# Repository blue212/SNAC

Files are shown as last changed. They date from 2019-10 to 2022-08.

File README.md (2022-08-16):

# SNAC
Accessory converter for MiSTer

Serial Native Accessory Converter

SNAC is general purpose level shifter for use with MiSTer. It can be used to power 5v devices and it will safely convert any logic between the 3v3(MiSTer) and 5 device. It will be used mostly for 5v controllers and other peripherals.

The SNAC connects to the User port(formerly Serial I/O port) of the IO board on Mister. I recommend a male to female usb3 extension cable between them.

The SNAC is available in 2 versions the only difference being the connector on the controller side(USB3 or HDMI). Various adapters can then be plugged into that connector. I made various adapter PCBs for use with the USB3 verrsion.

Becasue the SNAC connects to the User port the peripheral connects to the GPIO of the MiSTer, this bypasses all layers the normal usb controllers use. So it's very much like having a controller port for the original system. One benefit of this is that most weird peripherals should work with their cores(like Lightguns etc) which most normal usb converters either don't or can't do. One downside to bypassing the layers is the you can't controle the OSD.

*A mod to the older IO boards is needed if you want to use SEGA peripherals. Analog IO board 6.1 and Digital 1.2 fix this issue and have a jumper near USER port that needs to be set to io6 .

-TODO detail the needed mod

-Updates

Changed the partslist to use a different part for the male USB connector.

Uxcell a19032000ux0260 instead of Wuerth 692112030100

Addded Mini version of the hdmi and USB3 snac boards.

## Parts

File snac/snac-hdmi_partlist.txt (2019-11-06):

Partlist

Part     Value                          Device                         Package                     Library                                                  Sheet

C1       0.1uf                          C_0805                         C0805                       rc-master-smd                                            1
C2       0.1uf                          C_0805                         C0805                       rc-master-smd                                            1
JP1      PINHD-1X10_2.54-S              PINHD-1X10_2.54-S              1X10-S                      pinhead-2                                                1
JP2      PINHD-1X10_2.54-S              PINHD-1X10_2.54-S              1X10-S                      pinhead-2                                                1
JP3                                     JUMPER-2PTH                    1X02                        SparkFun                                                 1
K2       a19032000ux0260                a19032000ux0260                a19032000ux0260           Uxcell 1
K3       685119134923                   685119134923                   685119134923                Wuerth_Elektronik_eiCan_Communication_Connectors_STENCIL 1
Q1       BSS138                         MOSFET-NCHANNELSMD             SOT23-3                     SparkFun                                                 1
Q2       BSS138                         MOSFET-NCHANNELSMD             SOT23-3                     SparkFun                                                 1
Q3       BSS138                         MOSFET-NCHANNELSMD             SOT23-3                     SparkFun                                                 1
Q4       BSS138                         MOSFET-NCHANNELSMD             SOT23-3                     SparkFun                                                 1
Q5       BSS138                         MOSFET-NCHANNELSMD             SOT23-3                     SparkFun                                                 1
Q6       BSS138                         MOSFET-NCHANNELSMD             SOT23-3                     SparkFun                                                 1
Q7       BSS138                         MOSFET-NCHANNELSMD             SOT23-3                     SparkFun                                                 1
Q8       BSS138                         MOSFET-NCHANNELSMD             SOT23-3                     SparkFun                                                 1
R1       10K                            RESISTOR0603-RES               0603-RES                    SparkFun                                                 1
R2       10K                            RESISTOR0603-RES               0603-RES                    SparkFun                                                 1
R3       10K                            RESISTOR0603-RES               0603-RES                    SparkFun                                                 1
R4       10K                            RESISTOR0603-RES               0603-RES                    SparkFun                                                 1
R5       10K                            RESISTOR0603-RES               0603-RES                    SparkFun                                                 1
R6       10K                            RESISTOR0603-RES               0603-RES                    SparkFun                                                 1
R7       10K                            RESISTOR0603-RES               0603-RES                    SparkFun                                                 1
R8       10K                            RESISTOR0603-RES               0603-RES                    SparkFun                                                 1
R9       10K                            RESISTOR0603-RES               0603-RES                    SparkFun                                                 1
R10      10K                            RESISTOR0603-RES               0603-RES                    SparkFun                                                 1
R11      10K                            RESISTOR0603-RES               0603-RES                    SparkFun                                                 1
R12      10K                            RESISTOR0603-RES               0603-RES                    SparkFun                                                 1
R13      10K                            RESISTOR0603-RES               0603-RES                    SparkFun                                                 1
R14      10K                            RESISTOR0603-RES               0603-RES                    SparkFun                                                 1
R15      10K                            RESISTOR0603-RES               0603-RES                    SparkFun                                                 1
R16      10K                            RESISTOR0603-RES               0603-RES                    SparkFun                                                 1
U1       PMIC-LDO-XC6206P332MR-G(SOT23) PMIC-LDO-XC6206P332MR-G(SOT23) SOT-23                      PMIC-LDO-XC6206P332MR-G_SOT23_                           1
X1       JST-XH-02-PIN-ROUND-PAD        JST-XH-02-PIN-ROUND-PAD        JST-XH-02-PACKAGE-ROUND-PAD Rembrandt Electronics - JST XH Connectors v1-0           1

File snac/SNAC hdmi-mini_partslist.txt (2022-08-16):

Partlist

EAGLE Version 7.7.0 Copyright (c) 1988-2016 CadSoft

Assembly variant: 

Part     Value                          Package         Library                          Position (inch)       Orientation

C1       1uf                            C0805           rc-master-smd                    (0.23239998 0.06189998) MR0
C2       1uf                            C0805           rc-master-smd                    (0.42249975 0.062)    MR0
K2       a19032000ux0260                a19032000ux0260 Uxcell 1                         (0.2 0.444)           R90
K3       685119134923                   685119134923    Wuerth_Elektronik                (0.58 0.435)          R90 
Q1       BSS138                         SOT23-3         SparkFun                         (0.722 0.248)         MR90
Q2       BSS138                         SOT23-3         SparkFun                         (0.588 0.55)          MR90
Q3       BSS138                         SOT23-3         SparkFun                         (0.587 0.348)         MR90
Q4       BSS138                         SOT23-3         SparkFun                         (0.729 0.441)         MR90
Q5       BSS138                         SOT23-3         SparkFun                         (0.729 0.628)         MR90
Q6       BSS138                         SOT23-3         SparkFun                         (0.728 0.811)         MR90
Q7       BSS138                         SOT23-3         SparkFun                         (0.737 0.072)         MR90
R1       10K                            0603-RES        SparkFun                         (0.242 0.588)         MR180
R2       10K                            0603-RES        SparkFun                         (0.244 0.498)         MR180
R3       10K                            0603-RES        SparkFun                         (0.244 0.411)         MR180
R4       10K                            0603-RES        SparkFun                         (0.85910002 0.24680007) MR0
R5       10K                            0603-RES        SparkFun                         (0.855 0.441)         MR0
R6       10K                            0603-RES        SparkFun                         (0.242 0.671)         MR180
R7       10K                            0603-RES        SparkFun                         (0.859 0.54)          MR0
R8       10K                            0603-RES        SparkFun                         (0.242 0.752)         MR180
R9       10K                            0603-RES        SparkFun                         (0.857 0.63)          MR0
R10      10K                            0603-RES        SparkFun                         (0.854 0.333)         MR0
R11      10K                            0603-RES        SparkFun                         (0.24 0.842)          MR180
R12      10K                            0603-RES        SparkFun                         (0.853 0.812)         MR0
R13      10K                            0603-RES        SparkFun                         (0.242 0.328)         MR180
R14      10K                            0603-RES        SparkFun                         (0.86 0.058)          MR0
U1       PMIC-LDO-XC6206P332MR-G(SOT23) SOT-23          PMIC-LDO-XC6206P332MR-G_SOT23_   (0.299 0.2)           MR0

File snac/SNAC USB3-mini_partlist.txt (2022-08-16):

Partlist

EAGLE Version 7.7.0 Copyright (c) 1988-2016 CadSoft

Assembly variant: 

Part     Value                          Package         Library                          Position (inch)       Orientation

C1       1uf                            C0805           rc-master-smd                   (0.23239998 0.06189998) MR0
C2       1uf                            C0805           rc-master-smd                   (0.42249975 0.062)    MR0
K1       692121030100                   692121030100    Wuerth_Elektronik               (1.86 0.42)           R270
K2       a19032000ux0260                a19032000ux0260 Uxcell                          (0.2 0.42)            R90
Q1       BSS138                         SOT23-3         SparkFun                        (0.734 0.194)         MR90
Q2       BSS138                         SOT23-3         SparkFun                        (0.729 0.565)         MR90
Q3       BSS138                         SOT23-3         SparkFun                        (0.73 0.317)          MR90
Q4       BSS138                         SOT23-3         SparkFun                        (0.729 0.441)         MR90
Q5       BSS138                         SOT23-3         SparkFun                        (0.729 0.689)         MR90
Q6       BSS138                         SOT23-3         SparkFun                        (0.728 0.811)         MR90
Q7       BSS138                         SOT23-3         SparkFun                        (0.731 0.072)         MR90
R1       10K                            0603-RES        SparkFun                        (0.242 0.588)         MR180
R2       10K                            0603-RES        SparkFun                        (0.244 0.498)         MR180
R3       10K                            0603-RES        SparkFun                        (0.244 0.411)         MR180
R4       10K                            0603-RES        SparkFun                        (0.86210002 0.19380007) MR0
R5       10K                            0603-RES        SparkFun                        (0.855 0.441)         MR0
R6       10K                            0603-RES        SparkFun                        (0.242 0.671)         MR180
R7       10K                            0603-RES        SparkFun                        (0.856 0.565)         MR0
R8       10K                            0603-RES        SparkFun                        (0.242 0.752)         MR180
R9       10K                            0603-RES        SparkFun                        (0.853 0.689)         MR0
R10      10K                            0603-RES        SparkFun                        (0.859 0.317)         MR0
R11      10K                            0603-RES        SparkFun                        (0.24 0.842)          MR180
R12      10K                            0603-RES        SparkFun                        (0.853 0.812)         MR0
R13      10K                            0603-RES        SparkFun                        (0.242 0.328)         MR180
R14      10K                            0603-RES        SparkFun                        (0.861 0.071)         MR0
U1       PMIC-LDO-XC6206P332MR-G(SOT23) SOT-23          PMIC-LDO-XC6206P332MR-G_SOT23_  (0.299 0.2)           MR0

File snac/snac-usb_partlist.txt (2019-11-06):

Partlist

Part     Value                          Package                     Library                                                  Position (inch)       Orientation

C1       1uf                            C0805                       rc-master-smd                                            (0.16839998 0.07589998) R0
C2       1uf                            C0805                       rc-master-smd                                            (0.50849975 0.119)    R90
JP1      PINHD-1X10_2.54-S              1X10-S                      pinhead-2                                                (1.08 0.07)           R0
JP2      PINHD-1X10_2.54-S              1X10-S                      pinhead-2                                                (1.09 0.77)           R0
JP3                                     1X02                        SparkFun                                                 (0.393 0.772)         R0
K1       692121030100                   692121030100                Wuerth_Elektronik_eiCan_Communication_Connectors_STENCIL (1.86 0.42)           R270
K2       a19032000ux0260               a19032000ux0260              Uxcell                                                   (0.2 0.42)            R90
Q1       BSS138                         SOT23-3                     SparkFun                                                 (0.567 0.423)         R0
Q2       BSS138                         SOT23-3                     SparkFun                                                 (1.016 0.423)         R0
Q3       BSS138                         SOT23-3                     SparkFun                                                 (0.719 0.423)         R0
Q4       BSS138                         SOT23-3                     SparkFun                                                 (0.868 0.423)         R0
Q5       BSS138                         SOT23-3                     SparkFun                                                 (1.19 0.42)           R0
Q6       BSS138                         SOT23-3                     SparkFun                                                 (1.34 0.42)           R0
Q7       BSS138                         SOT23-3                     SparkFun                                                 (1.49 0.42)           R0
Q8       BSS138                         SOT23-3                     SparkFun                                                 (1.64 0.42)           R0
R1       10K                            0603-RES                    SparkFun                                                 (0.865 0.271)         R0
R2       10K                            0603-RES                    SparkFun                                                 (0.719 0.205)         R0
R3       10K                            0603-RES                    SparkFun                                                 (0.566 0.273)         R0
R4       10K                            0603-RES                    SparkFun                                                 (0.56689998 0.62480007) R180
R5       10K                            0603-RES                    SparkFun                                                 (0.862 0.626)         R180
R6       10K                            0603-RES                    SparkFun                                                 (1.02 0.2)            R0
R7       10K                            0603-RES                    SparkFun                                                 (1.016 0.573)         R180
R8       10K                            0603-RES                    SparkFun                                                 (1.191 0.271)         R0
R9       10K                            0603-RES                    SparkFun                                                 (1.185 0.625)         R0
R10      10K                            0603-RES                    SparkFun                                                 (0.715 0.574)         R180
R11      10K                            0603-RES                    SparkFun                                                 (1.337 0.203)         R0
R12      10K                            0603-RES                    SparkFun                                                 (1.34 0.57)           R0
R13      10K                            0603-RES                    SparkFun                                                 (1.491 0.27)          R0
R14      10K                            0603-RES                    SparkFun                                                 (1.49 0.622)          R0
R15      10K                            0603-RES                    SparkFun                                                 (1.641 0.329)         R0
R16      10K                            0603-RES                    SparkFun                                                 (1.641 0.568)         R0
U1       PMIC-LDO-XC6206P332MR-G(SOT23) SOT-23                      PMIC-LDO-XC6206P332MR-G_SOT23_                           (0.36 0.111)          R0
X1       JST-XH-02-PIN-ROUND-PAD        JST-XH-02-PACKAGE-ROUND-PAD Rembrandt Electronics - JST XH Connectors v1-0           (1.672 0.156)         R270

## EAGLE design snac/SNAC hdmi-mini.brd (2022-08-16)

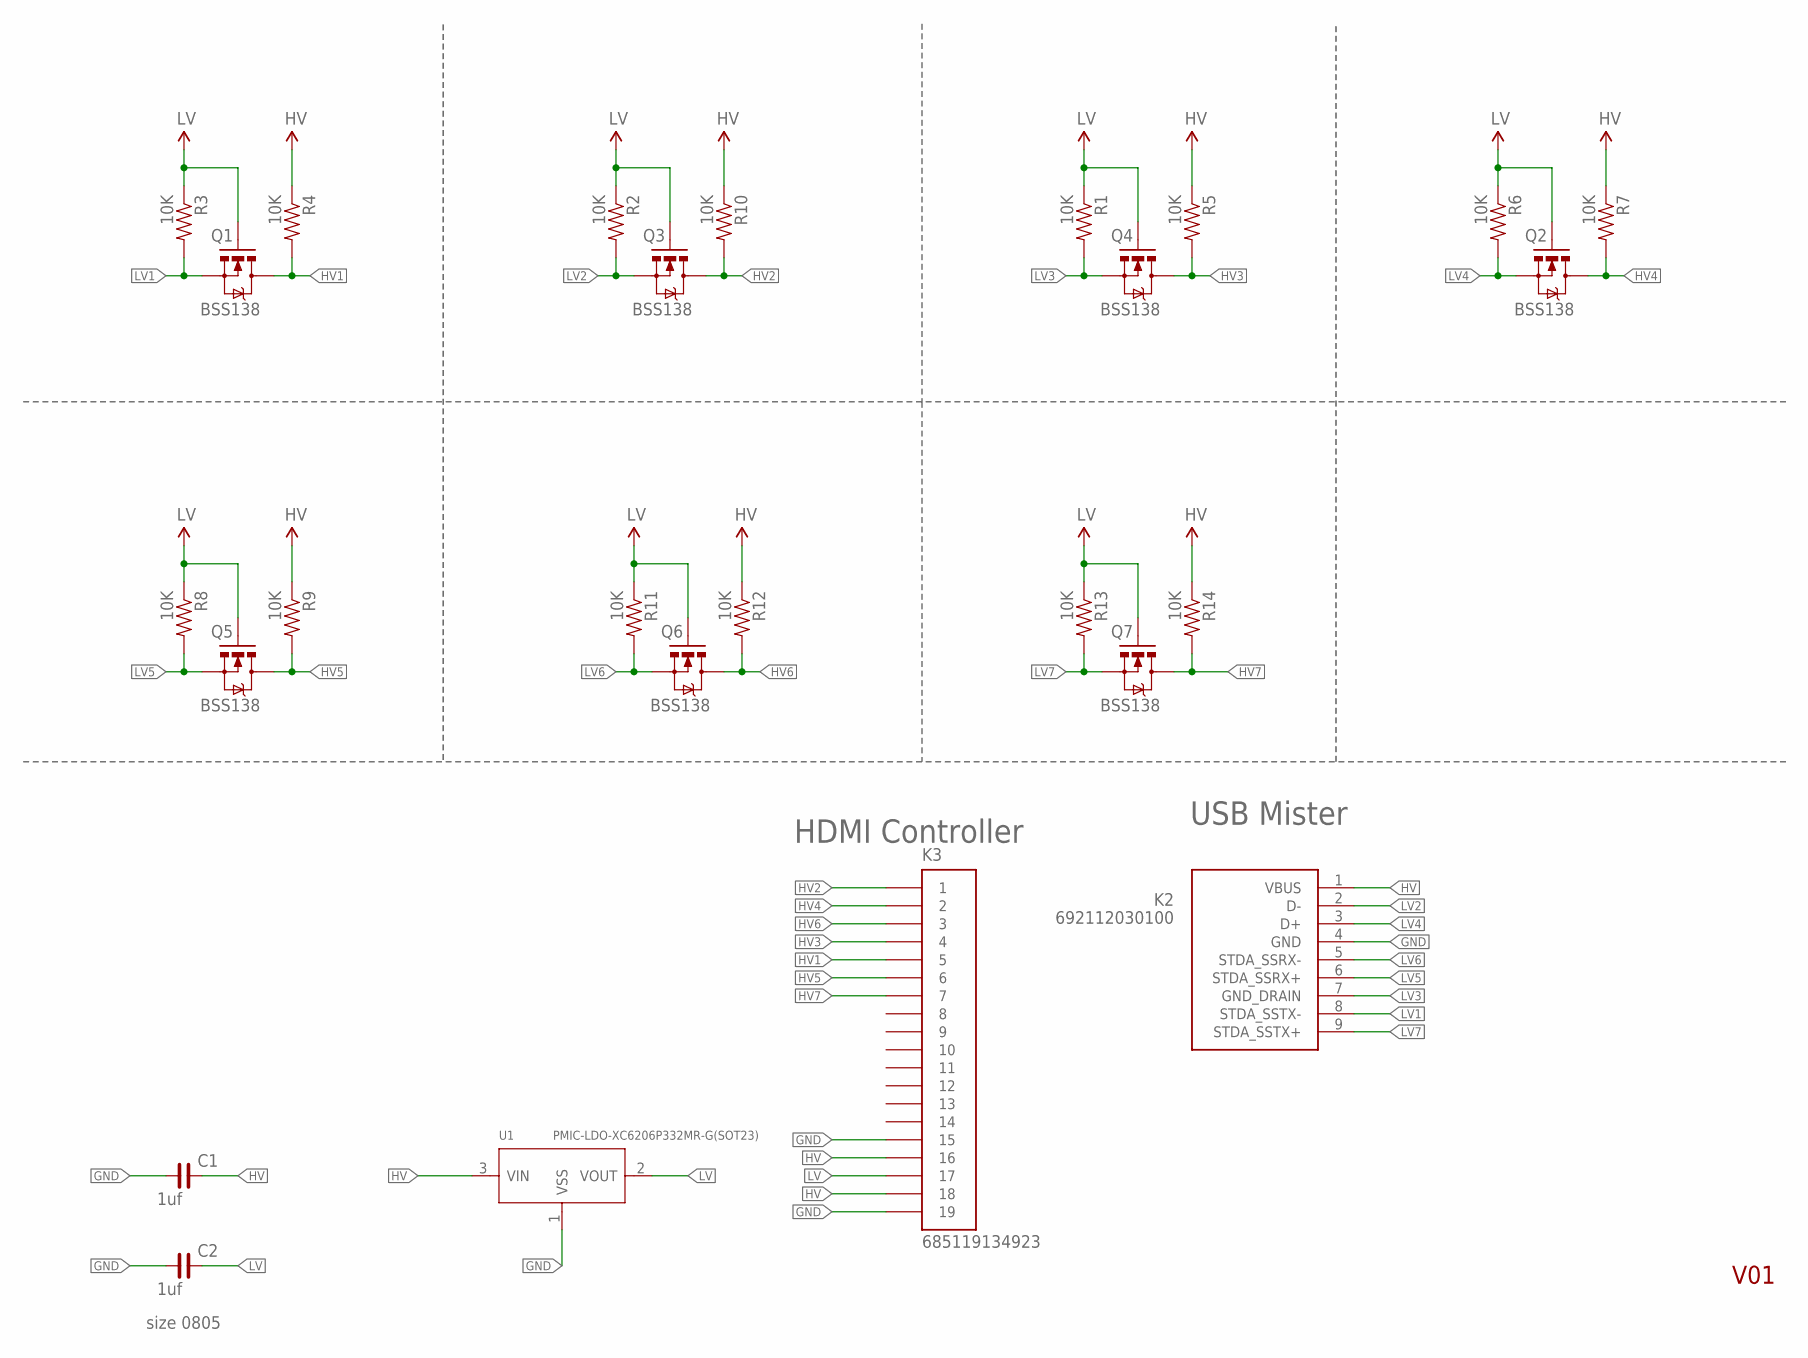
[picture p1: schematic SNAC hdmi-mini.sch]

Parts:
C1, C2: 1uf; C0805
K2: 692112030100
K3: 685119134923
Q1, Q2, Q3, Q4, Q5, Q6, Q7: BSS138; SOT23-3
R1, R2, R3, R4, R5, R6, R7, R8, R9, R10, R11, R12, R13, R14: 10K; 0603-RES
U1: PMIC-LDO-XC6206P332MR-G(SOT23); SOT-23

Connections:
GND: C1.1, C2.1, K2.4 (GND), K3.15, K3.19, U1.1 (VSS)
HV: C1.2, K2.1 (VBUS), K3.16, K3.18, R4.1, R5.1, R7.1, R9.1, R10.1, R12.1, R14.1, U1.3 (VIN)
HV1: K3.5, Q1.3 (D), R4.2
HV2: K3.1, Q3.3 (D), R10.2
HV3: K3.4, Q4.3 (D), R5.2
HV4: K3.2, Q2.3 (D), R7.2
HV5: K3.6, Q5.3 (D), R9.2
HV6: K3.3, Q6.3 (D), R12.2
HV7: K3.7, Q7.3 (D), R14.2
LV: C2.2, K3.17, Q1.1 (G), Q2.1 (G), Q3.1 (G), Q4.1 (G), Q5.1 (G), Q6.1 (G), Q7.1 (G), R1.1, R2.1, R3.1, R6.1, R8.1, R11.1, R13.1, U1.2 (VOUT)
LV1: K2.8 (STDA_SSTX-), Q1.2 (S), R3.2
LV2: K2.2 (D-), Q3.2 (S), R2.2
LV3: K2.7 (GND_DRAIN), Q4.2 (S), R1.2
LV4: K2.3 (D+), Q2.2 (S), R6.2
LV5: K2.6 (STDA_SSRX+), Q5.2 (S), R8.2
LV6: K2.5 (STDA_SSRX-), Q6.2 (S), R11.2
LV7: K2.9 (STDA_SSTX+), Q7.2 (S), R13.2

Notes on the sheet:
V01
USB Mister
size 0805
HDMI Controller

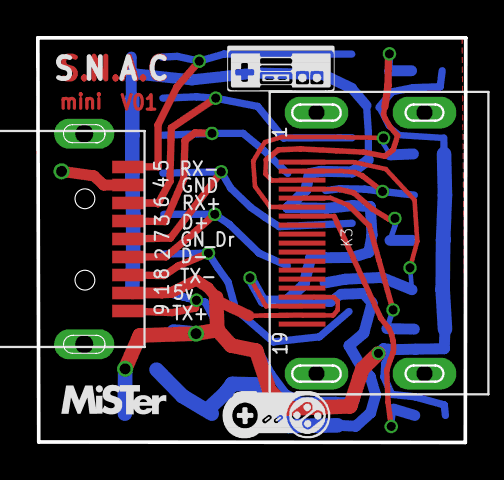
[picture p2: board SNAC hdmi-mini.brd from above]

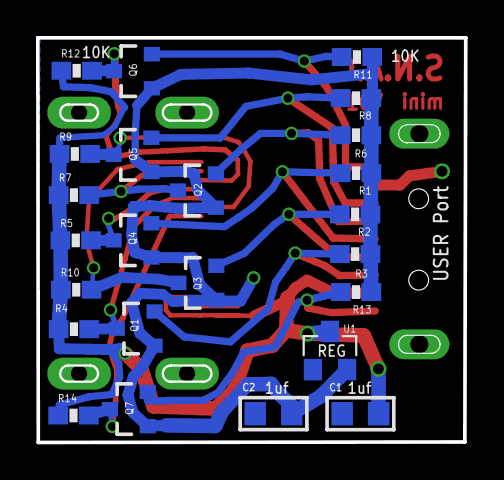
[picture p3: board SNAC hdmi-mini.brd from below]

Board: 2 copper layers, 23.8 x 22.5 mm, 26 parts (24 on the bottom side), 17 nets.

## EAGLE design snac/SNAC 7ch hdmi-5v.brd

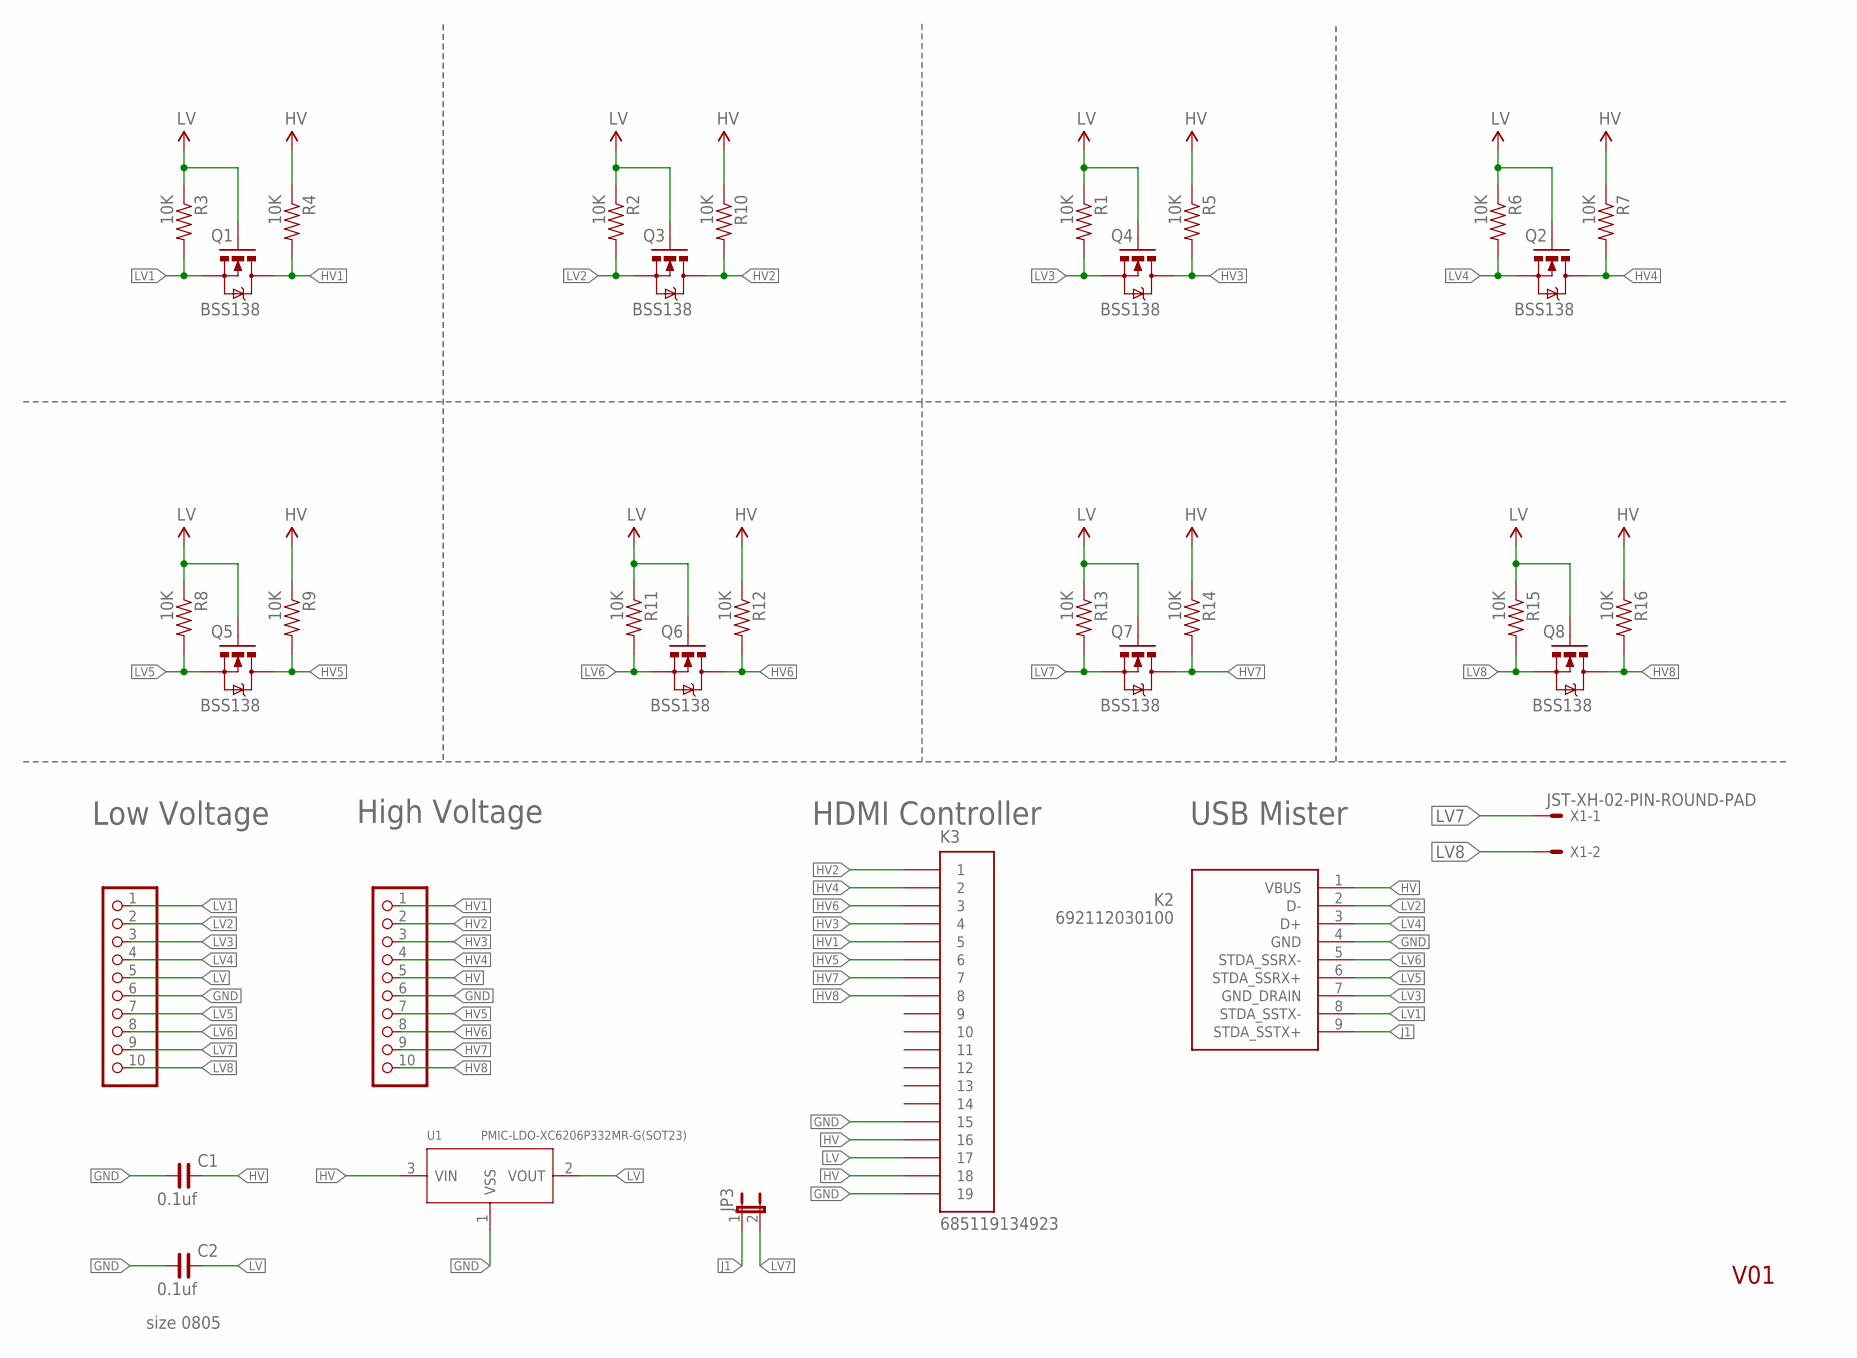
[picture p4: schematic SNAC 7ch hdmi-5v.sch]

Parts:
C1, C2: 0.1uf; C0805
JP1, JP2: PINHD-1X10_2.54-S; 1X10-S
JP3: JUMPER-2PTH; 1X02
K2: 692112030100
K3: 685119134923
Q1, Q2, Q3, Q4, Q5, Q6, Q7, Q8: BSS138; SOT23-3
R1, R2, R3, R4, R5, R6, R7, R8, R9, R10, R11, R12, R13, R14, R15, R16: 10K; 0603-RES
U1: PMIC-LDO-XC6206P332MR-G(SOT23); SOT-23
X1: JST-XH-02-PIN-ROUND-PAD; JST-XH-02-PACKAGE-ROUND-PAD

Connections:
GND: C1.1, C2.1, JP1.6, JP2.6, K2.4 (GND), K3.15, K3.19, U1.1 (VSS)
HV: C1.2, JP2.5, K2.1 (VBUS), K3.16, K3.18, R4.1, R5.1, R7.1, R9.1, R10.1, R12.1, R14.1, R16.1, U1.3 (VIN)
HV1: JP2.1, K3.5, Q1.3 (D), R4.2
HV2: JP2.2, K3.1, Q3.3 (D), R10.2
HV3: JP2.3, K3.4, Q4.3 (D), R5.2
HV4: JP2.4, K3.2, Q2.3 (D), R7.2
HV5: JP2.7, K3.6, Q5.3 (D), R9.2
HV6: JP2.8, K3.3, Q6.3 (D), R12.2
HV7: JP2.9, K3.7, Q7.3 (D), R14.2
HV8: JP2.10, K3.8, Q8.3 (D), R16.2
J1: JP3.1, K2.9 (STDA_SSTX+)
LV: C2.2, JP1.5, K3.17, Q1.1 (G), Q2.1 (G), Q3.1 (G), Q4.1 (G), Q5.1 (G), Q6.1 (G), Q7.1 (G), Q8.1 (G), R1.1, R2.1, R3.1, R6.1, R8.1, R11.1, R13.1, R15.1, U1.2 (VOUT)
LV1: JP1.1, K2.8 (STDA_SSTX-), Q1.2 (S), R3.2
LV2: JP1.2, K2.2 (D-), Q3.2 (S), R2.2
LV3: JP1.3, K2.7 (GND_DRAIN), Q4.2 (S), R1.2
LV4: JP1.4, K2.3 (D+), Q2.2 (S), R6.2
LV5: JP1.7, K2.6 (STDA_SSRX+), Q5.2 (S), R8.2
LV6: JP1.8, K2.5 (STDA_SSRX-), Q6.2 (S), R11.2
LV7: JP1.9, JP3.2, Q7.2 (S), R13.2, X1.1
LV8: JP1.10, Q8.2 (S), R15.2, X1.2

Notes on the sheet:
High Voltage
Low Voltage
V01
HDMI Controller
USB Mister
size 0805

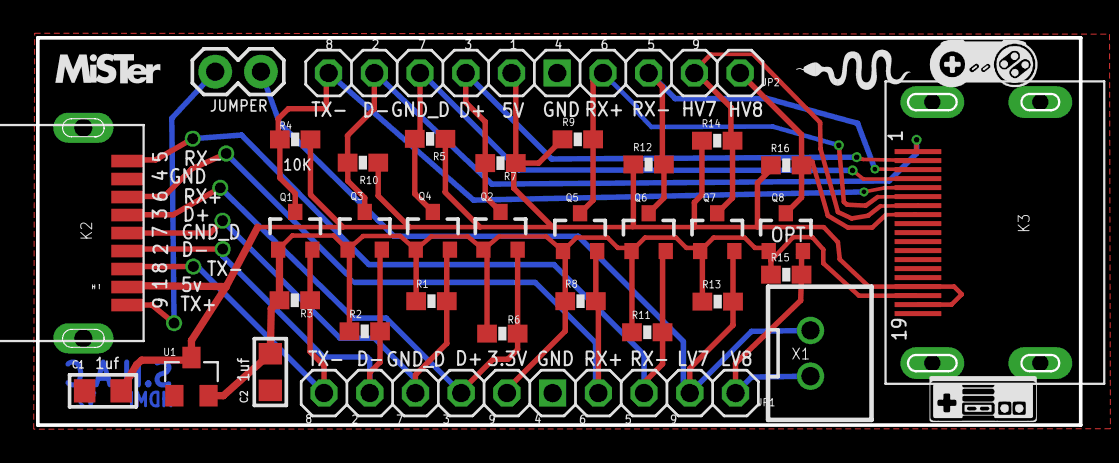
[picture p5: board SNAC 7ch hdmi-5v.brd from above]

Board: 2 copper layers, 57.9 x 21.5 mm, 33 parts (0 on the bottom side), 20 nets.

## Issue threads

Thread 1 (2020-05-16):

IO board mod on the IO board 6.1

L4ZZZ, 2020-05-16:
Hi,
I just wanted to know if I have to make the 7 pin mod on the IO board 6.1 in order to use a SEGA controller ?

Lessthan0tom, 2020-05-31:
The 6.1 IO board adds support for the 7th pin. You need to connect to two pins labeled "jumper" on the SNAC together for the 7th pin to work also

L4ZZZ, 2020-05-31:
And I suppose i have to connect those pins on the IO board too, right ?
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

Lessthan0tom, 2020-06-01:
I beleive that is correct. Looking at the board visually, you want to jump
the middle pin to the one labeled IO on the pins near the port. I am not
familiar with the schematic but it looks like that would be the position
connecting 2 and 3 at a glance.

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

L4ZZZ, 2020-06-01:
Alright, thanks for your help.

Closed 2020-06-01.

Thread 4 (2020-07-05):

6.0 io mod for genesis

Televicious, 2020-07-05:
Hi I have 6.0 io and wiring and connector for the mod, vut the only detail I have is the the snac has the connector soldered on and a wire is run with a resistor to the 6.0 board on pin 7. Is there a schematic or anything detailing the wiring of this mod?

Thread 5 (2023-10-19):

When is 3.3v jumper required and no io7 jumper on usb mini?

abishur, 2023-10-19:
I have a digital IO board and am trying to figure out when to have the jumper between IO6 and 3.3v or IO6 and I/O or not jumpered at all.  Is there any SNAC adapter where I would NEED to have it jumpered to 3.3v?

Also I've noticed for 2 player snac adapters I'm supposed to put a jumper on io7, but I made a USB Mini SNAC board.  Will it still be able to do 2 players?

blue212, 2023-10-28:
You can leave the jumper in the IO6 position on IO board, Nothing currently uses the 3v3 from user port.
The mini SNAC eliminated the extra jumper, and anything that uses the last IO will work as long as you have the jumper on IO board set.

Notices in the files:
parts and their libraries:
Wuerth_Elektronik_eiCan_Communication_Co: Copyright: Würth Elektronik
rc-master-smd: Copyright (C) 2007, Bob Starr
